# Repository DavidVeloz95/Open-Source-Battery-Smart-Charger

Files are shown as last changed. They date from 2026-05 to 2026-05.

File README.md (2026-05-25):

# Open Battery Smart Charger

Smart 2S Li-Ion battery charger designed in KiCad featuring input protection, power-path management, and intelligent charging control.

---

## Overview

This project implements an intelligent battery charging system for **2-cell Li-Ion batteries (8.4V)** with integrated protection and automatic power switching.

The system combines:

- Smart charging control
- Input overvoltage and overcurrent protection
- Automatic source/battery switching
- Auxiliary regulated 3.3V rail
- Battery monitoring interfaces

The design was developed in **KiCad 10** as part of a hardware/electronics engineering portfolio project.

---

## Features

- 2S Li-Ion battery charging (8.4V)
- Constant-current / constant-voltage (CC/CV) charging
- Input surge and fault protection
- Power-path management between external supply and battery
- Reverse current protection
- 3.3V regulated output for embedded systems
- Thermistor input for battery temperature supervision
- System and battery voltage interfaces

---

## System Architecture

### 1. Input Protection Stage

The input stage is protected using the **TPS26600** eFuse, providing:

- Overvoltage protection (OVP)
- Current limiting
- Fault protection
- Hot-plug robustness

This stage protects downstream electronics from abnormal supply conditions.

### 2. Smart Battery Charger

Battery charging is managed using the **LT3650**, configured for:

- 2S Li-Ion battery charging
- Constant-current / constant-voltage charging profile
- Battery temperature monitoring
- Charging status feedback

### 3. Power Path Management

The **LTC4412** controller enables automatic switching between:

- External DC power source
- Battery supply

This ensures uninterrupted system operation while preventing reverse current paths.

### 4. Auxiliary Power Rail

A dedicated **3.3V LDO regulator** powers low-voltage logic and embedded systems.

---

## Main Components

| Component | Function |
|---|---|
| LT3650 | Smart battery charger |
| TPS26600 | Input protection / eFuse |
| LTC4412 | Ideal diode power-path controller |
| LDK320AM33R | 3.3V voltage regulator |

---

## Specifications

| Parameter | Value |
|---|---|
| Battery Type | 2S Li-Ion |
| Charge Voltage | 8.4V |
| Charging Method | CC/CV |
| Logic Rail | 3.3V |
| Input Protection | OVP / current limiting |
| Design Tool | KiCad 10 |

---

## Repository Structure

```text
Open_Battery_Charger/
│
├── hardware/
│   ├── Open_Battery_Charger.kicad_pro
│   ├── Open_Battery_Charger.kicad_sch
│   ├── Open_Battery_Charger.kicad_pcb
│   └── fp-lib-table
│
├── docs/
│   ├── schematic.pdf
│   ├── schematic.png
│   ├── 2D_pcb_top.png
│   ├── 2D_pcb_bottom.png
│   ├── 3D_pcb_top.png
│   ├── 3D_pcb_bottom.png
│   ├── Detailed_Design_Procedure_LT3650.pdf
│   ├── Detailed_Design_Procedure_TPS2660
│   └── Open_Source_Battery_Smart_Charger_Specifications.pdf
│
└── production/
    ├── gerbers/
    └── bom.csv
```

---

## Schematic

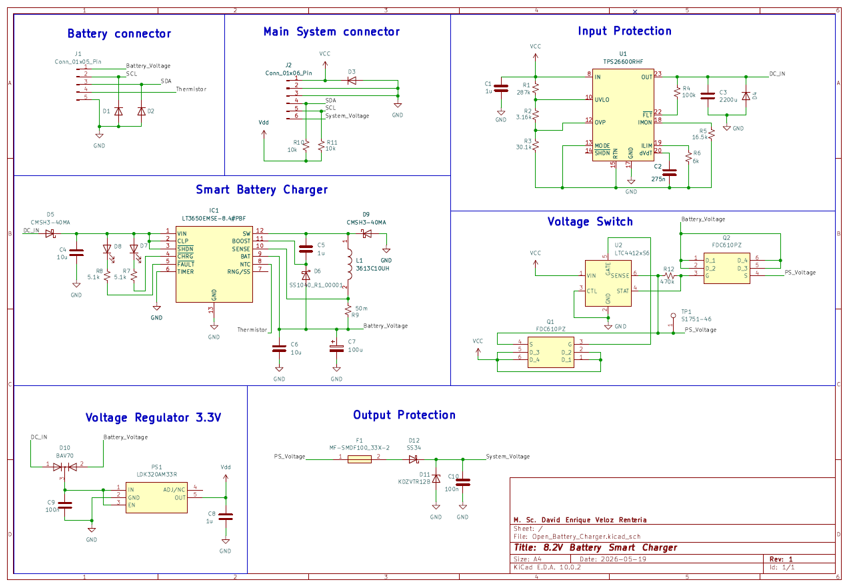
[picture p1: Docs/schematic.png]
Schematic


---

## PCB Design

### Top View

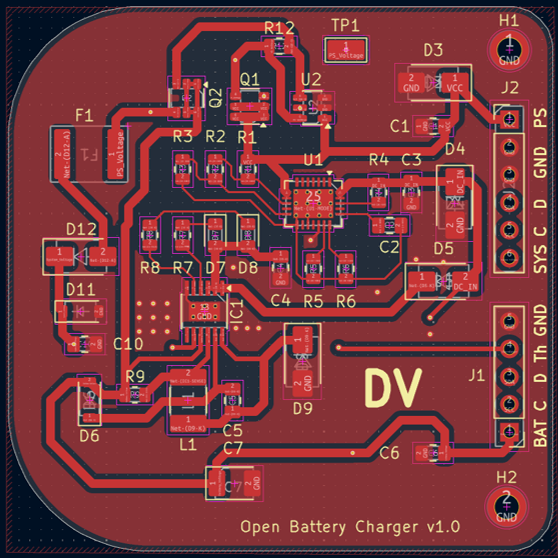
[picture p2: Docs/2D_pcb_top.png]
PCB Top


### 3D Render

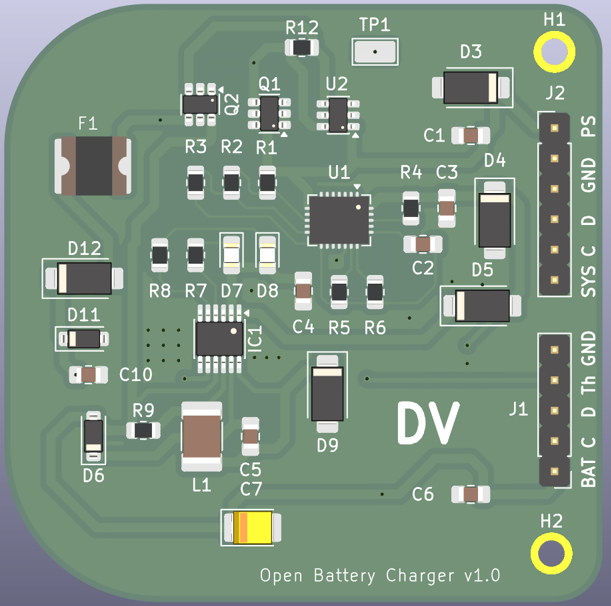
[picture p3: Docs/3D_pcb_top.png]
PCB Render


---

## Design Considerations

Key engineering decisions considered during development:

- Input fault protection for safer operation
- Efficient battery charging profile implementation
- Automatic power source switching
- Low-voltage regulation for embedded systems
- Modular architecture for maintainability

---

## Tools

- KiCad 10
- Datasheet-driven design methodology
- Electronic circuit validation

---

## Future Improvements

- PCB manufacturing and validation
- Thermal characterization
- Charging efficiency measurements
- Test reports and oscilloscope captures
- Firmware integration for battery monitoring

---

## License

This project is released under the MIT License.

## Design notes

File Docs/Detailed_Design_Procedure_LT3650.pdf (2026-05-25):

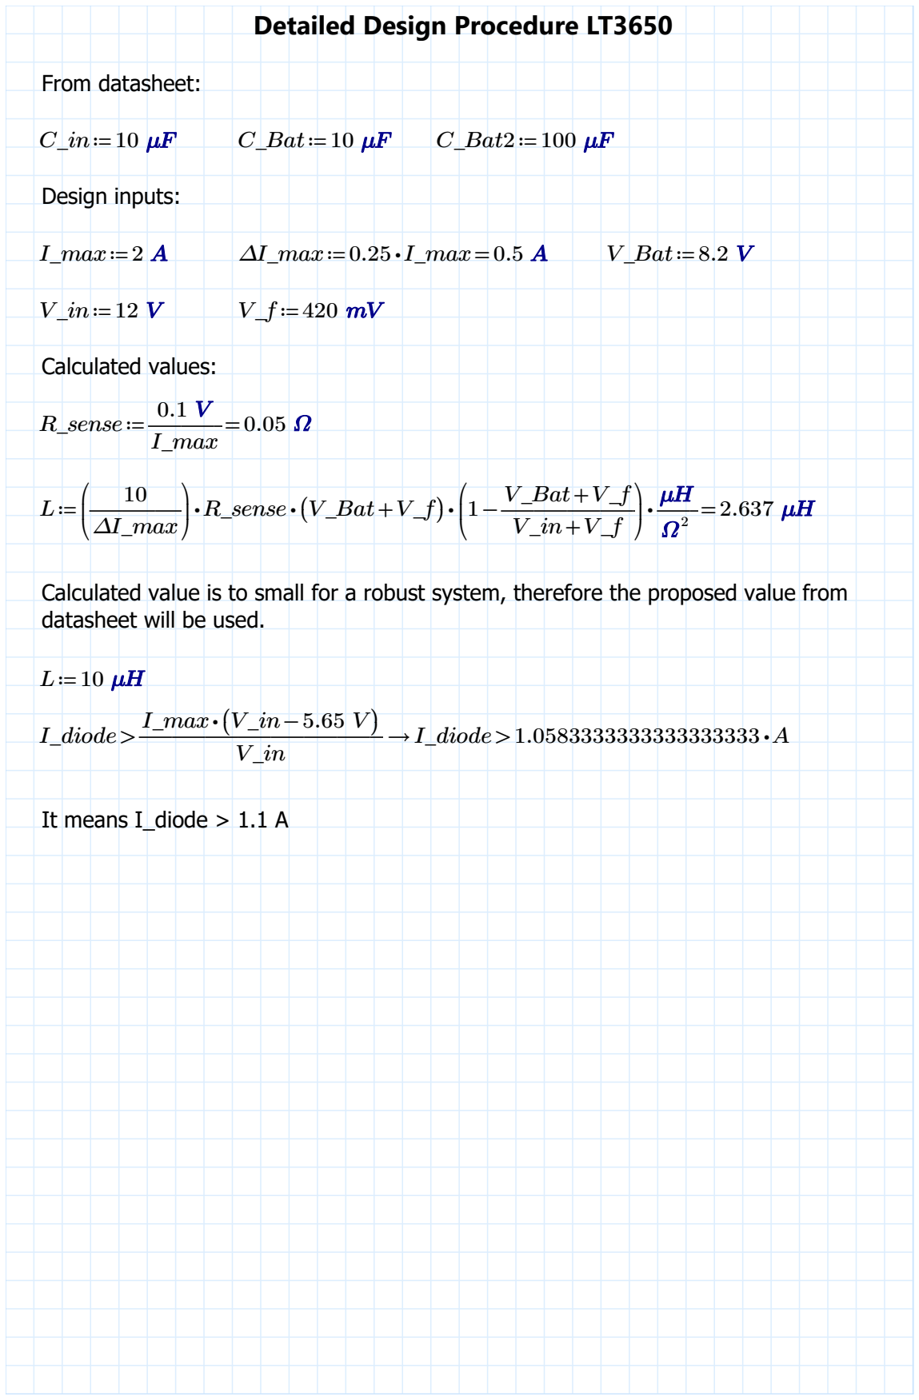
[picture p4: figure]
Detailed Design Procedure LT3650; From datasheet:; C_Bat≔10 μF; C_Bat2≔100 μF; Design inputs:; Calculated values:; R_sense≔―――=; 0.1 V I_max; ― ΔI_max; R_sense; ((V_Bat+V_f)); 1-―V_Bat ――+V_f ―― V_in+V_f; datasheet will be used.; I_diode>――――――――→; I_max⋅ ((V_in-5.65; I_diode>1.0583333333333333333 ⋅A; It means I_diode > 1.1 A

I_max≔2 A | ΔI_max≔0.25 ⋅ I_max=0.5 A | V_Bat≔8.2 V

Calculated value is to small for a robust system, therefore the proposed value from

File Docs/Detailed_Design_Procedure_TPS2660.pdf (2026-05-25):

### Detailed Design Procedure TPS2660

Design parameters:
Vin = 12V
Vov = 12.6V
Vuv = 11.4V
RL(su) = 12Ω
Ilim = 2A
Cout = 2200μF

Undervoltage Lockout and Overvoltage Protection

From datasheet V_ovpr = 1.19V and V_uvlor = 1.19V.

V_ovpr≔1.19 V | V_uvlor≔1.19 V

Overvoltage protection (Ov = 12.6V) and Undervoltage protection (Uv = 11.4V). Values are from power supply (AKM45US12).

Ov≔12.6 V | Uv≔11.4 | V
Resistor values calculated starting with R3 = 30.1 kΩ | and equations from datasheet.
X = R1+R2+R3.
R3≔30.1 | kΩ | X≔―――⋅ | =

R3
V_ovpr
| | | | Ov 318.706 | kΩ
R2≔―――⋅ | - | =

V_uvlor
Uv
X | R3 | 3.168 | kΩ | R1≔X-R2-R3=285.437 | kΩ

Looking for real resistor values (case code 0805 in) available on Mouser Electronics:

R1≔287 kΩ | R2≔3.16 kΩ | R3≔30.1 kΩ

Calculating new Voltage values:

V_ov≔V_ovpr ⋅―――――=

((R1+R2+R3))
| | R3 | | 12.661 V

V_uv≔V_uvlor ⋅―――――=

((R1+R2+R3))
R2+R3
| | | | 11.458 V

Active Current Limiting

Propossed System max. current (2A) shall be the limit. The equation comes from datasheet:

I_ol≔2 A | R_ilim≔―――=
| | | | 12 kV I_ol 6 kΩ

Using a real resistor value R_ilim = 6 kΩ:

R_ilim≔6 | kΩ | I_lim≔―――=

### 12 kV

R_ilim

### 2 A

Input noise suppress

C_in has a typical capacitance value in range of 0.1 | μF to 1 | μF.

C_in≔1 μF

Current Monitoring Resistor

For I_lim=2A, and considering the operating voltage range of ADC from 0V to 2.5V:

V_IMONmax≔2.5 V

R_IMON≔――――――=

V_IMONmax
I_lim⋅ ⎛⎝75 ⋅ 10⁻⁶⎞
⎠
16.667 | kΩ | V≔I_lim⋅ ⎛⎝75 ⋅ 10 | ⋅ | =

-6⎞
⎠ | 16.5 kΩ | 2.475 | V

Real value for R_IMON:

R_IMON≔16.5 kΩ

Output Voltage Ramp Time

For an inrush current I_inrush=1A (estimated) shall be the t_dVdT calculated:

I_inrush≔1 A | C_out≔2200 μF | V_in≔12 | V

t_dVdT≔C_out⋅―――=

| | V_in
I_inrush
| | 65.34 ms

For a given start-up time, C_dVdT capacitance value is calculated: C_dVdT≔―t_dVdT ――⋅―1 A― ⋅ ⎛⎝8 ⋅ 10³ ⎞
⎠ V_in
| | C_dVdT=275 nF

The pull-up resistor (R4 or R_fltb) for the open-drain fault output shall have a value in
the range of 10 kΩ | to 100kΩ. The current sink by pin FLT must not exceed 10mA.
R_fltb≔100 | kΩ | I_flt≔―――=
| | 12 V R_fltb 0.297 mA

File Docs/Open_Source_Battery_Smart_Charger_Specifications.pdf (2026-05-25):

REFERENCE DESIGN – PORTFOLIO USE ONLY | DV

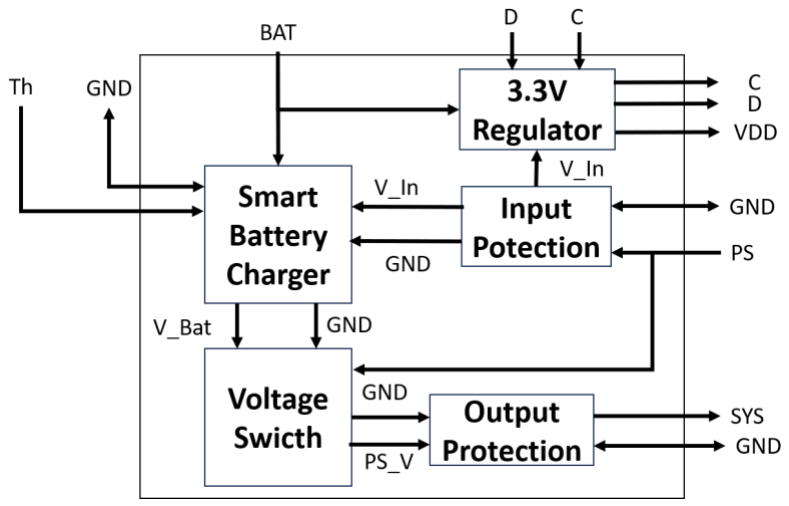
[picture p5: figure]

Revision: 1.0 Date: May 2026 This document is intended solely for engineering portfolio and reference purposes. © M. Sc. David Veloz. All rights reserved.

## Open-Source Battery Smart Charger Specifications

### 1. General Description

This design is intended to provide a flexible platform for providing power to an external device using 2S Li-Ion batteries or external DC Voltage source. The module provides 8.2V – 12V power to the external system continually whilst a battery pack or external DC supply is connected.

### 2. Board Overview

### 2.1. Architecture Block Diagramm

Figure 1: Architecture Block Diagramm.

### 2.2. Signal Description

Signal Name | Description
PS | Main power supply for the circuit
GND | Ground reference
BAT | Battery voltage
Th | Analog thermistor signal
SYS | System Power Supply
VDD | 3.3V regulated power supply
C | I2C bus clock line
D | I2C bus data line
Table 1: Signal Description.

### 2.3. Pin Configuration Battery Connector (J1)

Pin
No.
Symbol | Type
1 | BAT | Battery Power
2 | C | Digital Clock
3 | D | Digital Bidirectional Data
4 | Th | Analog Sense
5 | GND | Ground Reference
Table 2: Battery Connector Pin Definition.

### 2.4. Pin Configuration System Connector (J2)

Pin
No.
Symbol | Type
1 | PS | Power Supply
2 | GND | Ground Reference
3 | GND | Ground Reference
4 | D | Digital Bidirectional Data
5 | C | Digital Clock
6 | SYS | External System Power Supply
Table 3: System Connector Pin Definition.

### 3. Mechanical Specifications

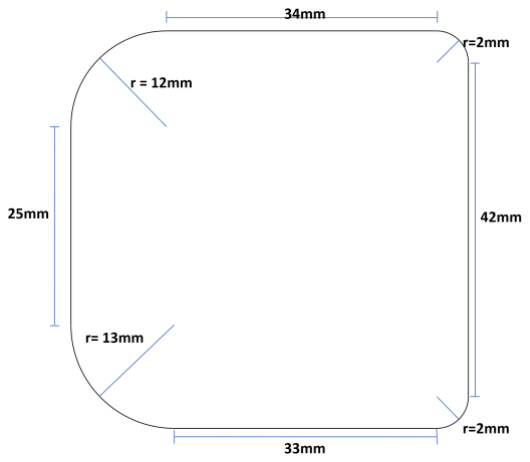
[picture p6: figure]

Figure 2: Board Dimensions.

### 4. Reference Schematics

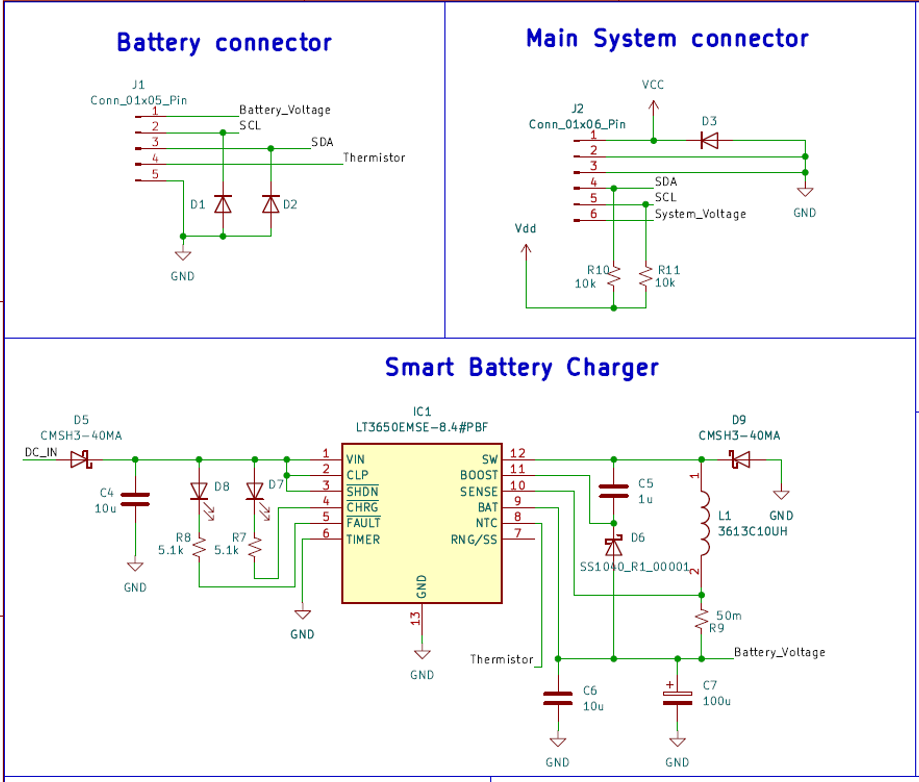
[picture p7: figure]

Figure 3: Connectors and Battery Charger circuitry.

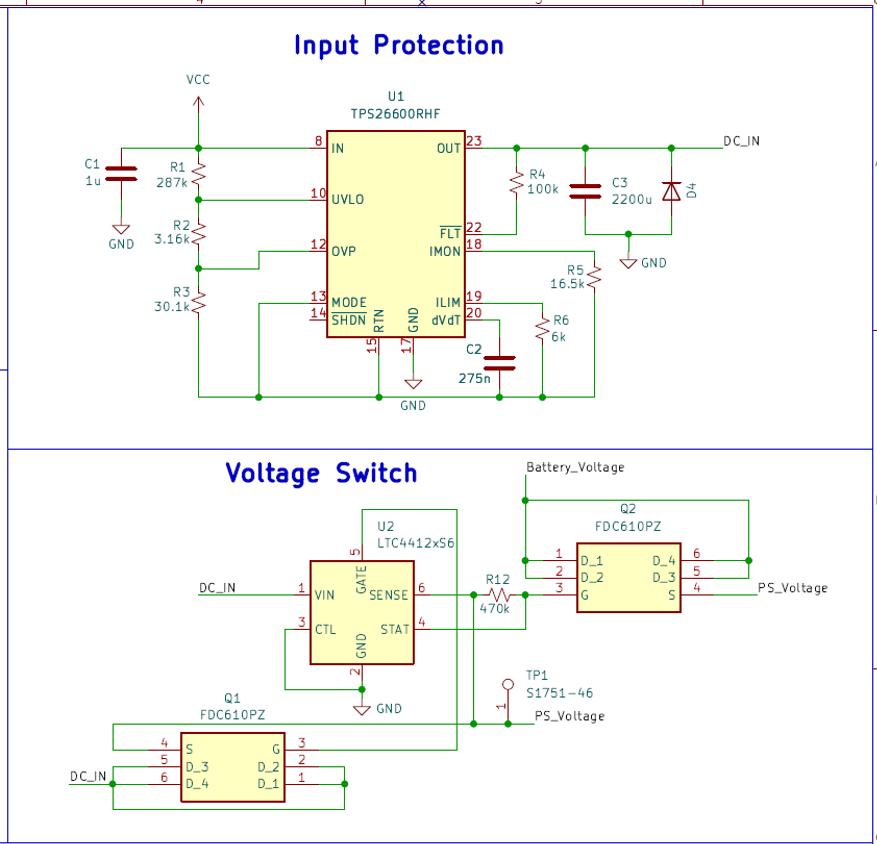
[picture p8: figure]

Figure 4: Input protection circuit and voltage switcher.

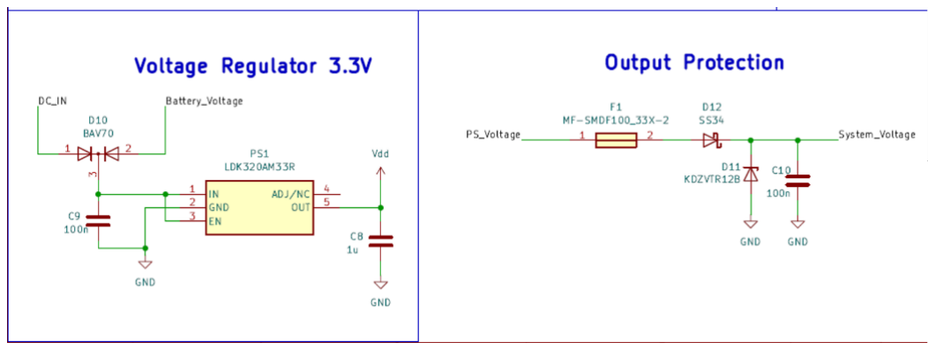
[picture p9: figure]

Figure 5: 3.3V Regulator and output protection circuit.

### 5. Board Specifications 5.1. Absolute Maximum Ratings, TA=25°C

Parameters | Min. | Max. | Unit
Supply Voltage | 12 | 12 | V
Input Over Voltage Protection | - | 12.6 | V
Charging Voltage | - | 8.4 | V
Charging Current | - | 2000 | mA
Charge mode | CC/CV
Reverse polarity protection | Yes
Thermistor support | Yes
Input Fuse | 1A polyfuse
Logic I2C Voltage | - | 3.3 | V
Table 4: Electrical Specifications.

### 6. Main Components Specifications 6.1. Input Protection (TPS26600)

The circuitry is protected from the connection from an incompatible DC Power Supply. The protection circuit has the following features:
- Undervoltage Lockout at 11.4V
- Overvoltage protection at 12.6V
- Reverse current blocking

To reach the features a TPS26600 was selected. Circuitry, shown on Figure 4 – Input Protection, is the TPS26600 configuration to protect load from overvoltage, reverse voltage, etc.

Passive components were calculated following the next procedure:

System design parameters:

Vin = 12V
VOV = 12.6V
VUV = 11.4V
RL(su) = 12Ω
Ilim = 2A
COut = 2200μF

Undervoltage Lockout and Overvoltage Protection

From Datasheet VOVPR = 1.19V and VUVLOR = 1.19V.

Overvoltage protection (VOV = 12.6V) and Undervoltage protection VUV = 11.4V. Values come from power supply (AKM45US12). Resistor values calculated starting with R3 = 30.1kΩ and equations from datasheet.

X = R1 + R2 + R3

X =

R3

VOVPR

= 318.706 kΩ

R2 =

VUVLOR

VUV

= 3.168 kΩ

R1 = X − R2 − R3 = 285.437 kΩ

Looking for real resistor values with case code 0805 (in) available on Mouser Electronics:

R1 = 287 kΩ
R2 = 3.16 kΩ
R3 = 30.1 kΩ
Calculating new voltage values:

VOV = VOVPR ∙

R1 + R2 + R3
R3

= 12.661 V

VUV = VUVLOR ∙

R1 + R2 + R3
R2 + R3

= 11.458 V

Active Current Limiting

Proposed System max. current (2A) shall be the limit. The equations are from datasheet:

Rilim =

12

Ilim

= 6 kΩ

Input noise suppression

CIn has a typical capacitance value in range of 0.1μF to 1μF.

CIn = 1μF

Current Monitoring Resistor

For Ilim = 2A, and considering the operation voltage range of ADC from 0V to 2.5V:

VIMONmax = 2.5 V

RIMON =

VIMONmax
Ilim∙(75∙10⁻⁶)

= 16.667 kΩ V = Ilim ∙ (75 ∙ 10⁻⁶ ) ∙ 16.5 kΩ = 2.475 V

Real value for RIMON = 16.5 kΩ

Output Voltage Ramp Time

For an inrush current Iinrusℎ = 1 A (estimated) shall be the tdVdT calculated:

tdVdT = COut ∙

VIn

Iinrusℎ

= 65.34 ms

For a given start-up time, CdVdT capacitance value is calculated:

CdVdT =

tdVdT
(8 ∙ 10³) ∙ VIn

= 275 nF

The pull-up resistor (R4 or Rfltb) for the open-drain fault output shall have a value in the range of 10 kΩ to 100 kΩ. The current sink by pin FLT must not exceed 10 mA.

Rfltb = 100 kΩ

Iflt =

12V

Rftlb

= 0.297 mA

### 6.2. Battery Charger (LT3650-8.4)

The battery pack can be charged from an external 12V ACDC power supply. For design the LT3650-8.4 was selected. Some features of the controller are:
- Constant-Current/constant-voltage charge
- 2A charging current
- Low battery and bad-battery detection
- Auto-restart mode if the battery voltage drops 2.5%

The LT3650 is a Li-Ion battery charger, which incorporates a 2 A switch that is driven by a bootstrapped supply to maximize efficiency during charging cycles. Once charging is terminated and the LT3650 is not actively charging, the IC automatically enters a low current standby mode in which supply bias currents are reduced to 85 μA. The IC monitors battery temperature by using a thermistor during charging cycle, suspends charging, and signals a fault condition if the battery temperature moves outside a safe charging range.

Passive components were calculated following the next procedure:

From datasheet we got the next values

Cin = 10 μF CBat = 10 μF CBat2 = 100 μF

The design inputs for this circuitry are:

Imax = 2 A | ΔImax = 0.25 ∙ Imax = 0.5 A VBat = 8.2 V Vin = 12 V | Vf = 420 mV

Then the calculated values for passive components are:

Rsense =

0.1 V

Imax

= 0.05 Ω

L = (

10

ΔImax

) ∙ Rsense ∙ (VBat + Vf) ∙ (1 − VBat + Vf

VIn + Vf

) = 2.637 μH

The calculated value is to small for a robust system, therefore the proposed value from datasheet will be used.

L = 10 μH

For diode election the next value is needed:

Idiode >

Imax ∙ (VIn − 5.65)

VIn

~1.0583 A

It means the Idiode > 1.1 A

### 6.3. Voltage Switch (LTC4412)

The LTC4412 controls an external P-Channel MOSFET for power switchover. When a wall adapter is connected the load is automatically disconnected from the battery. For this design the primary supply is the wall adapter. The capability of the automatic controller makes it feasible to use the IC without an external microcontroller.

### 6.4. Output Protection

The fuse used protects the circuit from overcurrents and short circuits; it does not blow or suffer permanent damage but is capable of automatically resuming normal operation after cooling down. In addition, a Schottky diode is used to provide reverse current protection, along with a Zener diode and a capacitor in parallel to prevent overvoltage clamping, absorb spikes, reduce ringing, and improve transient stability.

### 6.5. Voltage Regulator

The LDK320 is a voltage regulator, which provides a 3.3V output. The very good dynamic characteristic, combined with low drop voltage and low quiescent current make it suitable for this application. This device also includes short-circuit current limiting, thermal and safe operating area protection.

### 7. Performance

To verify that this circuit is working properly, the ideal outcome would be to obtain the following results.
- Full battery charge, with graphs showing Battery Charging Current (Ampere) vs Battery Charging Time Percentage (%); Battery Charging Current (Ampere) vs Battery Voltage (Voltage); Temperature (Celsius degree) while Battery Charging (%); Battery Voltage
(Voltage) while Battery charging (%); Power Supply Current (Ampere) while Battery charging (%); Power comparison (W) between circuit input (Power Supply) and output

(Battery) during charging process; Efficiency (%) vs Battery Charging Time Percentage (%).
- Battery discharge, graphically representing Temperature (°c) while Battery discharging; Battery Voltage while discharging with different loads.
- Simultaneous connection of the power supply and the fully charged battery, graphically representing efficiency.
- Battery discharge with loads varying over time, graphically representing performance.

### 8. Bill Of Materials

Reference | Value
C1,C5,C8 | 1u
C2 | 275n
C3 | 2200u
C4,C6 | 10u
C7 | 100u
C9,C10 | 100n
D1,D2,D3,D4 | SMAJ12A-HP6AT/13
D5,D9 | CMSH3-40MA
D6 | SS1040_R1_00001
D7 | Q62702P5179
D8 | Q62702P5178
D10 | BAV70
D11 | KDZVTR12B
D12 | SS34
F1 | MF-SMDF100_33X-2
IC1 | LT3650EMSE-8.4#PBF
J1 | Conn_01x05_Pin
J2 | Conn_01x06_Pin
L1 | 3613C10UH
PS1 | LDK320AM33R
Q1,Q2 | FDC610PZ
R1 | 287k
R2 | 3.16k
R3 | 30.1k
R4 | 100k
R5 | 16.5k
R6 | 6k
R7,R8 | 5.1k
R9 | 50m
R10,R11 | 10k
R12 | 470k
TP1 | S1751-46
U1 | TPS26600RHF
U2 | LTC4412xS6

### 9. Test Procedures 9.1. Funcitional Test

1. Do a visual inspection, verifying all connectors are well welded according to IPC-A-610E SP, all IC’s are correctly oriented, if PCB has scratches or any mechanical damage, also look for solder bridges.
2. Verify that J1 pin 1 (Battery_Voltage), J2 pin 1 (VCC) and pin 6 (System_Voltage), IC1 pin 1 (DC_IN), TP1 and connection between D1, D2, D3, D4, D9, D11 have non-connectivity with GND.
3. Connect J2 to AC/DC Wall Adapter 12V. D8 LED shall be OFF the whole time.
4. TP1 should have a value around 12V.
5. Connect a multimeter and an electric load at 2A to J2 (System_Voltage and GND).
6. Turn on the electronic load and look at the output voltage in oscilloscope. Voltage must be around 11.5V.
7. Turn off the electric load and disconnect J2 and connect battery pack to J1. D7 must turn on if Power Supply and Battery are connected simultaneously.
8. Repeat procedure instructions 4 to 6. But Voltages shall be between 5.2V and 8.4V.
9. Disconnect battery.

### 9.2. Discharging Test

1. Before continuing with this test, the functional test shall be approved.
2. Be sure Battery is full.
3. During this test is important to get the next values:
a. Battery current in Amperes.
b. Battery voltage in Volts.
c. Power Supply current in Amperes.
d. Power Supply voltage in Volts.
e. Temperature in Celsius.
4. To acquire each value is needed to use a specific connection. Connections shall be explained only if this board is manufactured because external custom boards or harnesses would be needed.
5. Connect harness at J2.
6. Identify System_Voltage and GND pins. Connect an electric load to them.
7. Connect the battery and set the electric load at 2A.
8. After doing the connections to measure data, turn on the electric load.
9. When battery is empty, turn off the electric load and stop data acquisition. Save the data.
10. Disconnect all and storage the equipment as specified in laboratory instructions.

### 9.3. Charging Test

1. Before continuing with this test, the functional test shall be approved.
2. Be sure Battery is empty.
3. During this test is important to get the next values:
a. Battery current in Amperes.
b. Battery voltage in Volts.
c. Power Supply current in Amperes.

d. Power Supply voltage in Volts.
e. Temperature in Celsius.
4. To acquire each value is needed to use a specific connection. Connections shall be explained only if this board is manufactured because external custom boards or harnesses would be needed.
5. Connect harness at J2.
6. Connect the battery and the Power Supply. Harness J2 will have a DC Jack connector.
7. Connect Power Supply to AC Socket.
8. When battery is full, disconnect Power Supply and stop data acquisition. Save the data.
9. Disconnect all and storage the equipment as specified in laboratory instructions.

### 10.Equipment needed

The equipment needed to run the tests to this circuit is:
- Digital Multimeter
- Power Supply or Voltage Generator
- Temperature sensor
- Electronic Load

### 11.Design Inputs

Requirement: The circuit should be protected from the connection from an incompatible DC Power Supply. The protection circuit should have the following features:
- Reverse Polarity Protection
- Overvoltage protection
Actions: TPS26600 provides over voltage protection at 12.6V since it is considered that Power Supplies normally have variations at output, having a protection exactly at 12 V will limit the supplies that can be used, while operating range is 60V and reverse input polarity protection is -60V.

Requirement: The battery should be charged from an external 12V ACDC power supply. A compatible barrel jack connector should be used with the DC Supply.
Actions: Components are configured to work with an external 12V ACDC Power Supply (AKM45US12).

Requirement: The board should pass the output voltage directly from the charging circuit to the device output without alteration.
Actions: There is no internal regulator for main voltage output. Value at input is almost the same value at the output, it depends on the characteristics from Supply with a load.

Requirement: SMBus pins should be exposed on the output connector. Logic levels should be 3.3V. Actions: Communication logical voltage is provided by LDK320AM33R.

Requirement: The output of the board should be protected in such a way that failure in either the external load or the board itself should not damage the other module.
To mitigate this risk the board should provide the following output protection features.
- Overcurrent protection outside of supply specification.
- Over voltage protection outside of supply specification.

Actions: To solve an unfortunate failure as overcurrent or over voltage there is a diode (KDZVTR12B) and fuse (MF-SMDF100_33X-2) arrangement to provide protection to module that is connected to the board.

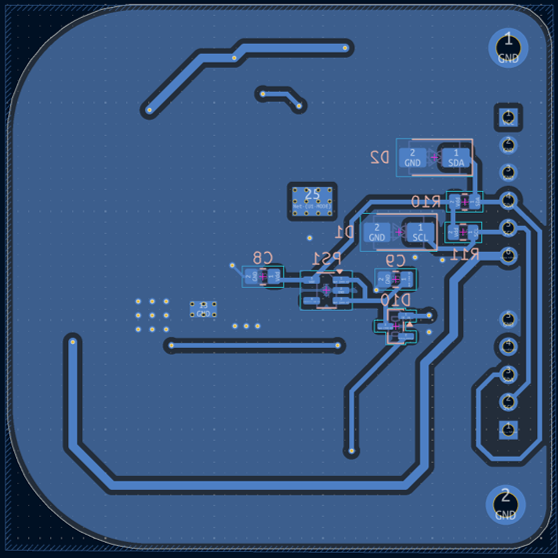
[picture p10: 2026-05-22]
Docs/2D_pcb_bottom.png

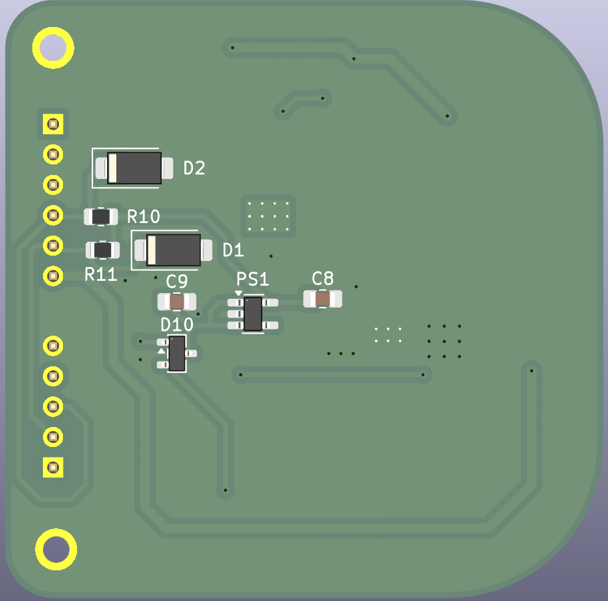
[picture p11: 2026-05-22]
Docs/3D_pcb_bottom.png

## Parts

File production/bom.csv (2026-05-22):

Bill Of Materials (BOM)
# | Reference | Qty | Value | Descripción | Product Number | Manufacturer | Price
1 | C1,C5,C8 | 3 | 1u | Unpolarized capacitor
2 | C2 | 1 | 275n | Unpolarized capacitor
3 | C3 | 1 | 2200u | Unpolarized capacitor
4 | C4,C6 | 2 | 10u | Unpolarized capacitor
5 | C7 | 1 | 100u | TLJP107M004R2700
6 | C9,C10 | 2 | 100n | Unpolarized capacitor
7 | D1,D2,D3,D4 | 4 | SMAJ12A-HP6AT/13 | ESD Protection Diodes / SMAJ DO214AC TVS Diodes 12V–19.9V AEC-Q101 | SMAJ12A-HP6AT/13 | YAGEO | 0,396
8 | D5,D9 | 2 | CMSH3-40MA | Schottky diode
9 | D6 | 1 | SS1040_R1_00001 | Schottky diode
10 | D7 | 1 | Q62702P5179 | Light emitting diode
11 | D8 | 1 | Q62702P5178 | Light emitting diode
12 | D10 | 1 | BAV70 | Dual 100V 215mA high-speed switching diodes, common cathode, SOT-23
13 | D11 | 1 | KDZVTR12B | Zener diode
14 | D12 | 1 | SS34 | 40V 3A Schottky Diode, SMA
15 | F1 | 1 | MF-SMDF100_33X-2 | Resettable Fuses - PPTC PTC RESETTABLE 1.1A 33V SMD 2018
16 | IC1 | 1 | LT3650EMSE-8.4#PBF | Battery Management High Voltage 2 Amp Monolithic 2-Cell Li-Ion Battery Charger
17 | J1 | 1 | Conn_01x05_Pin | Generic connector, single row, 01x05, script generated
18 | J2 | 1 | Conn_01x06_Pin | Generic connector, single row, 01x06, script generated
19 | L1 | 1 | 3613C10UH | Fixed Inductors 250 mAmps +/- 10% 10 uH
20 | PS1 | 1 | LDK320AM33R | LDO Voltage Regulators 200 mA low quiescent current and high PSRR voltage regulator
21 | Q1,Q2 | 2 | FDC610PZ | Max rDS(on) = 75m at VGS = -4.5V, ID = -3.7A; Low gate charge (17nC typical).; High performance trench technology for extremely low rDS(on). ; SuperSOT-6 package: small footprint (72% smaller than standard SO-8) low profile (1mm thick).; Max rDS(on) = 42m at VGS = -10V, ID = -4.9A; RoHS compliant
22 | R1 | 1 | 287k | Resistor, small US symbol
23 | R2 | 1 | 3.16k | Resistor, small US symbol
24 | R3 | 1 | 30.1k | Resistor, small US symbol
25 | R4 | 1 | 100k | Resistor, small US symbol
26 | R5 | 1 | 16.5k | Resistor, small US symbol
27 | R6 | 1 | 6k | Resistor, small US symbol
28 | R7,R8 | 2 | 5.1k | Resistor, small US symbol
29 | R9 | 1 | 50m | Resistor, small US symbol
30 | R10,R11 | 2 | 10k | Resistor, small US symbol,Thick Film Resistors - SMD General Purpose Chip Resistor 0805, 10kOhms, 5%, 1/8W | RC0805JR-7W10KL | YAGEO | 0,086
31 | R12 | 1 | 470k | Resistor, small US symbol
32 | TP1 | 1 | S1751-46 | Hardware: SMT Test Point 1.63x3.25mm 2mm high
33 | U1 | 1 | TPS26600RHF | 60V, 2A Current Limiting, Industrial eFuse, Reverse Current Blocking, Adjustable Overvoltage cut-off, Active Current Limiting, Circuit Breaker with auto-retry, VQFN-24
34 | U2 | 1 | LTC4412xS6 | Low Loss PowerPath Controller, TSOT-23-6

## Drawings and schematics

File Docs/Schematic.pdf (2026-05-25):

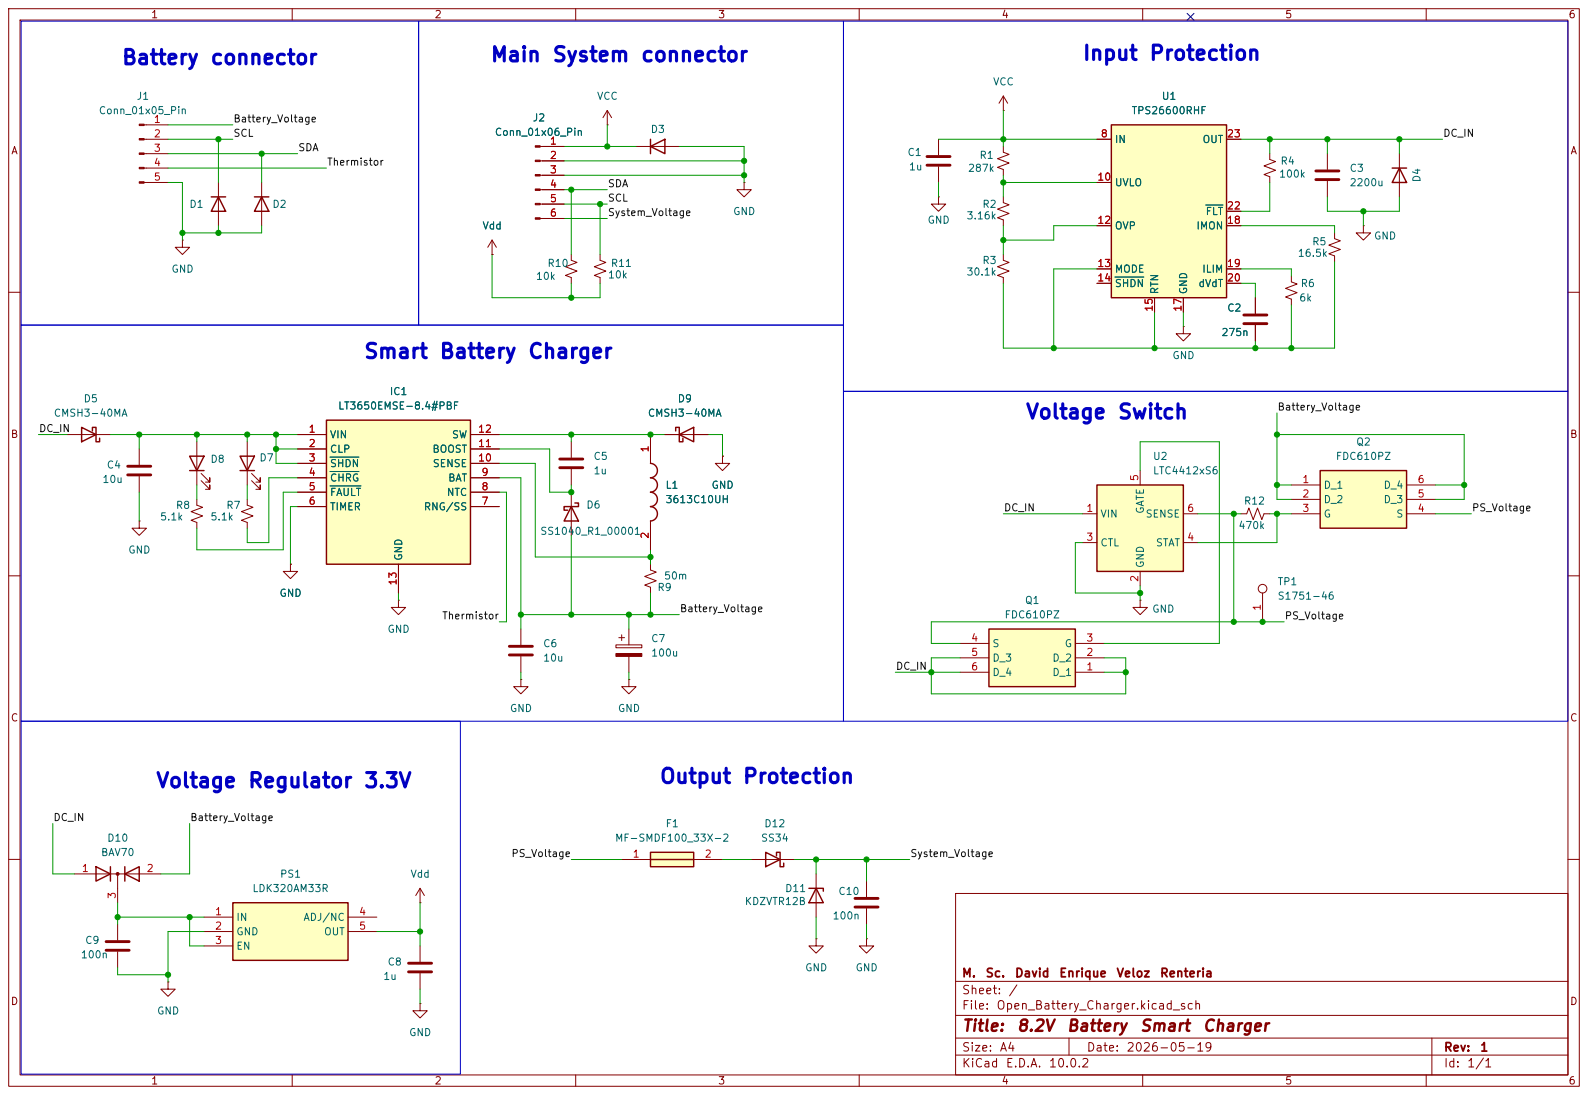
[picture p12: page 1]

M. Sc. David Enrique Veloz Renteria
Sheet: /
File: Open_Battery_Charger.kicad_sch
Title: 8.2V Battery Smart Charger

Size: A4 | Rev: 1
KiCad E.D.A. 10.0.2 | Id: 1/1

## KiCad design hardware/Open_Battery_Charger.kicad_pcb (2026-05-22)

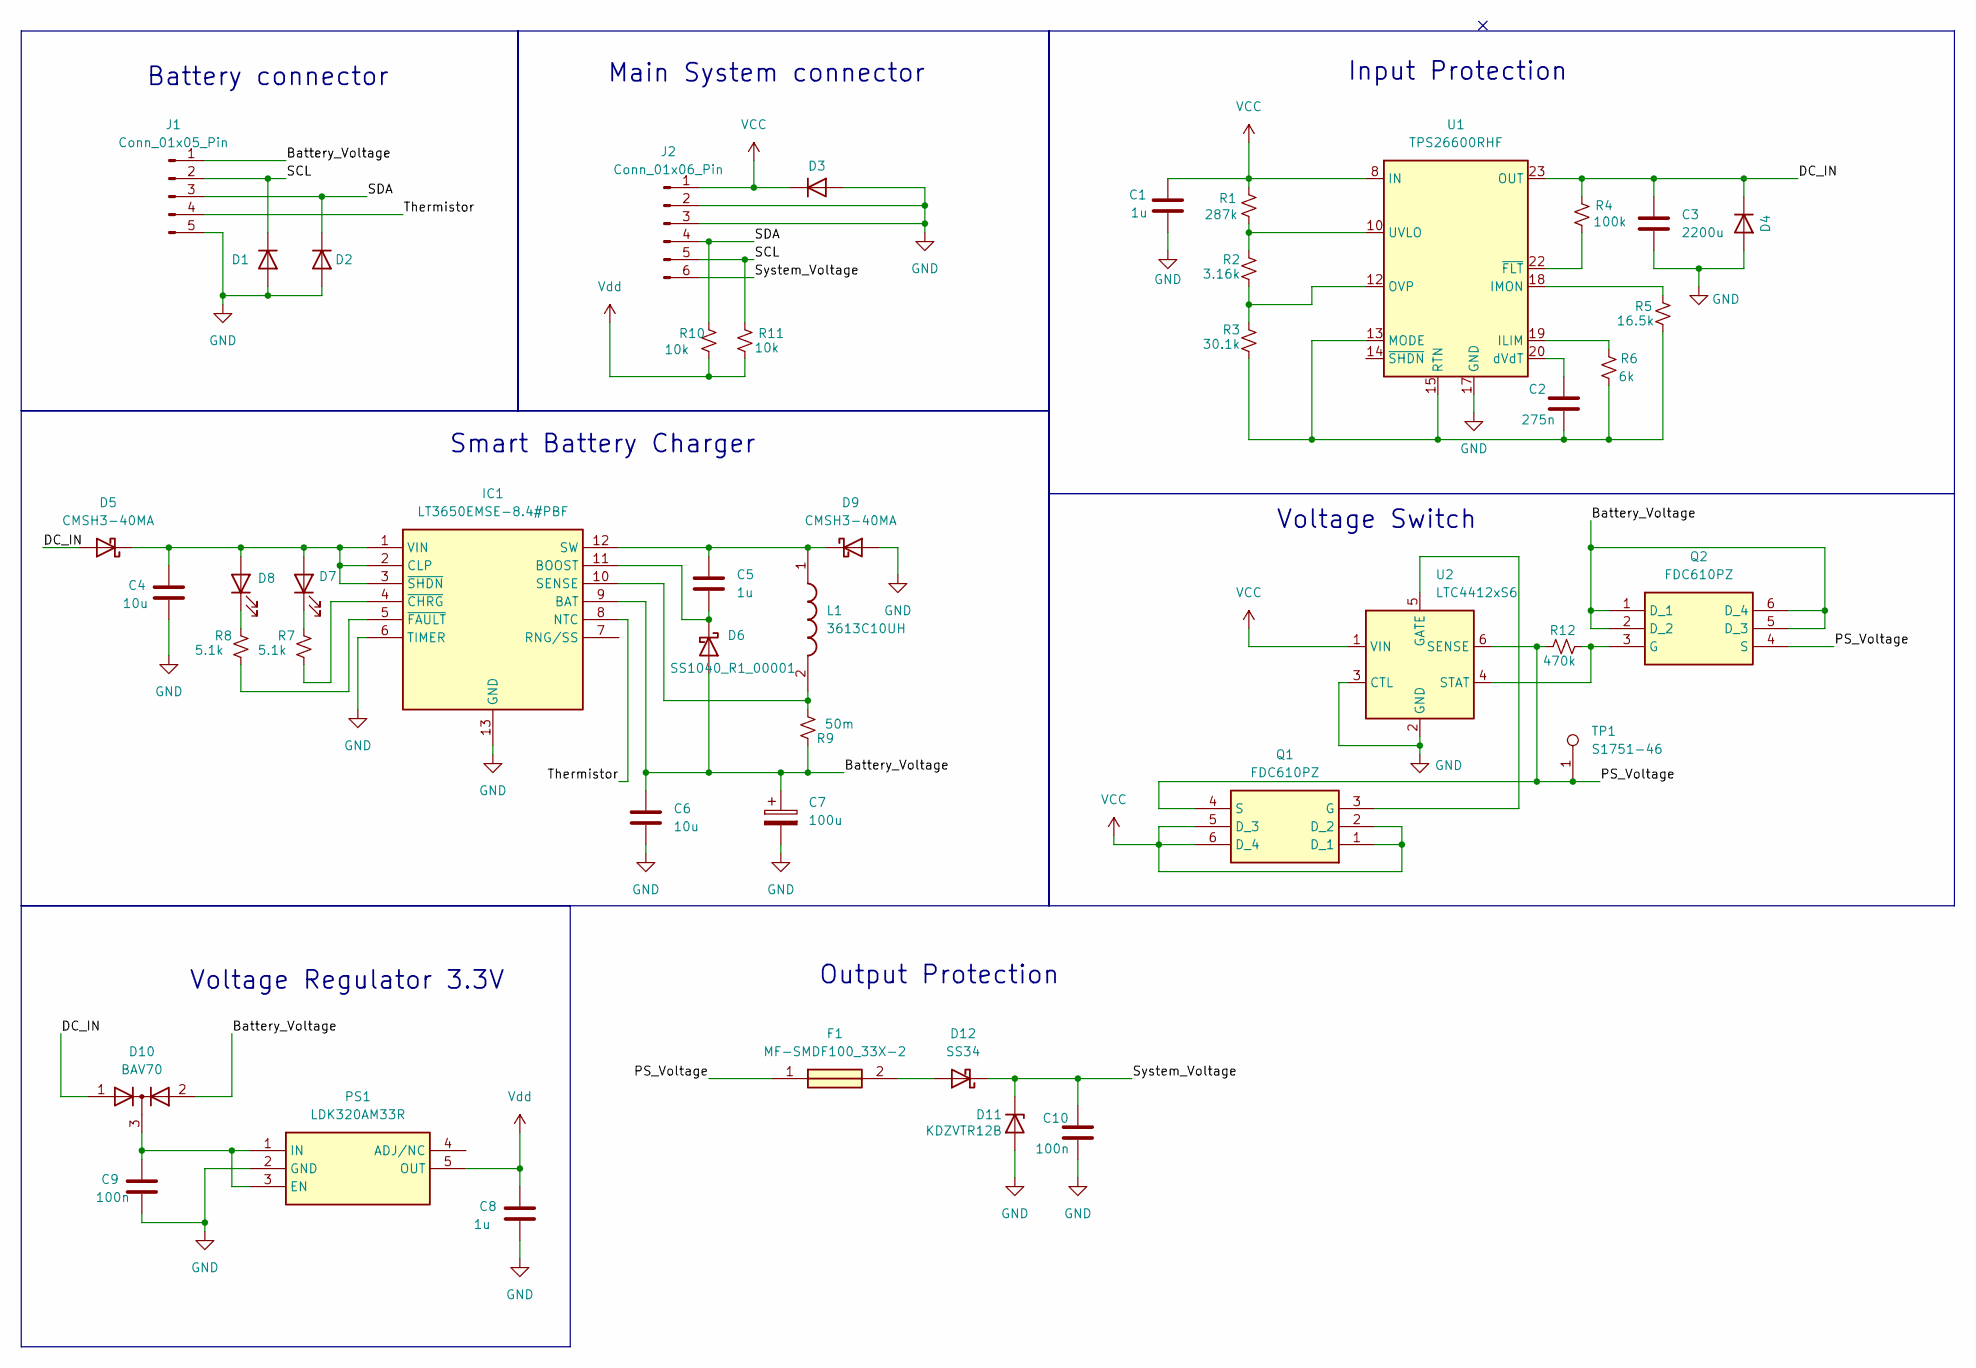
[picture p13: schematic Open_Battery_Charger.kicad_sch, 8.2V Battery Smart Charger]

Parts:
C1, C5, C8: 1u; C_0805_2012Metric_Pad1.18x1.45mm_HandSolder
C2: 275n; C_0805_2012Metric_Pad1.18x1.45mm_HandSolder
C3: 2200u; C_0805_2012Metric_Pad1.18x1.45mm_HandSolder
C4, C6: 10u; C_0805_2012Metric_Pad1.18x1.45mm_HandSolder
C7: 100u; CP_EIA-3528-21_Kemet-B_HandSolder
C9, C10: 100n; C_0805_2012Metric_Pad1.18x1.45mm_HandSolder
D1, D2, D3, D4: SMAJ12A-HP6AT/13; D_SMA
D5, D9: CMSH3-40MA; D_SMA
D6: SS1040_R1_00001; D_SOD-123
D7: Q62702P5179; LED_0805_2012Metric_Pad1.15x1.40mm_HandSolder
D8: Q62702P5178; LED_0805_2012Metric_Pad1.15x1.40mm_HandSolder
D10: BAV70; SOT-23
D11: KDZVTR12B; D_SOD-123
D12: SS34; D_SMA
F1: MF-SMDF100_33X-2; Mouser Part Number 652-MF-SMDF100/33X-2
IC1: LT3650EMSE-8.4#PBF; MSOP-12-1EP_3x4.039mm_P0.65mm_EP1.651x2.845mm_ThermalVias; Mouser Part Number 584-3650EMSE-8.4PBF
J1: Conn_01x05_Pin; PinHeader_1x05_P2.54mm_Vertical
J2: Conn_01x06_Pin; PinHeader_1x06_P2.54mm_Vertical
L1: 3613C10UH; C_1812_4532Metric_Pad1.57x3.40mm_HandSolder; Mouser Part Number 279-3613C10UH
PS1: LDK320AM33R; SOT-23-5_HandSoldering; Mouser Part Number 511-LDK320AM33R
Q1, Q2: FDC610PZ; SuperSOT-6; Mouser Part Number 512-FDC610PZ
R1: 287k; R_0805_2012Metric
R2: 3.16k; R_0805_2012Metric
R3: 30.1k; R_0805_2012Metric
R4: 100k; R_0805_2012Metric
R5: 16.5k; R_0805_2012Metric
R6: 6k; R_0805_2012Metric
R7, R8: 5.1k; R_0805_2012Metric
R9: 50m; R_0805_2012Metric
R10, R11: 10k; R_0805_2012Metric
R12: 470k; R_0805_2012Metric
TP1: S1751-46; TestPoint_Keystone_5015_Micro_Mini; Mouser Part Number 855-S1751-46
U1: TPS26600RHF; Texas_RHF0024A_VQFN-24-1EP_4x5mm_P0.5mm_EP2.65x3.65mm_Therm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
U2: LTC4412xS6; TSOT-23-6

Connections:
/Battery_Voltage: C6.1, C7.1, D6.2 (A), D10.2 (A), IC1.9 (BAT), J1.1, Q2.1 (D_1), Q2.2 (D_2), Q2.5 (D_3), Q2.6 (D_4), R9.1
/DC_IN: C3.1, D4.1 (K), D5.2 (A), D10.1 (A), R4.1, U1.23 (OUT), U1.24 (OUT)
/PS_Voltage: F1.1, Q1.4 (S), Q2.4 (S), R12.1, TP1.1, U2.6 (SENSE)
/SCL: D1.1 (K), J1.2, J2.5, R11.1
/SDA: D2.1 (K), J1.3, J2.4, R10.1
/System_Voltage: C10.1, D11.1 (K), D12.1 (K), J2.6
/Thermistor: IC1.8 (NTC), J1.4
GND: C1.1, C3.2, C4.2, C6.2, C7.2, C8.2, C9.2, C10.2, D1.2 (A), D2.2 (A), D3.2 (A), D4.2 (A), D9.2 (A), D11.2 (A), IC1.6 (TIMER), IC1.13 (GND), J1.5, J2.2, J2.3, PS1.2 (GND), U1.17 (GND), U2.2 (GND), U2.3 (CTL); also elsewhere on the board
unnamed: C4.1, D5.1 (K), D7.2 (A), D8.2 (A), IC1.1 (VIN), IC1.2 (CLP), IC1.3 (~SHDN)
unnamed: C5.2, D6.1 (K), IC1.11 (BOOST)
unnamed: D7.1 (K), R7.1
unnamed: D8.1 (K), R8.1
unnamed: C5.1, D9.1 (K), IC1.12 (SW), L1.1
unnamed: C9.1, D10.3 (K), PS1.1 (IN), PS1.3 (EN)
unnamed: D12.2 (A), F1.2
unnamed: IC1.10 (SENSE), L1.2, R9.2
unnamed: IC1.4 (~CHRG), R7.2
unnamed: IC1.5 (~FAULT), R8.2
unnamed: Q1.3 (G), U2.5 (GATE)
unnamed: Q2.3 (G), R12.2, U2.4 (STAT)
unnamed: R6.1, U1.19 (ILIM)
unnamed: R5.1, U1.18 (IMON)
unnamed: C2.2, R3.2, R5.2, R6.2, U1.13 (MODE), U1.15 (RTN), U1.25 (RTN)
unnamed: R2.2, R3.1, U1.12 (OVP)
unnamed: R1.2, R2.1, U1.10 (UVLO)
unnamed: C2.1, U1.20 (dVdT)
unnamed: R4.2, U1.22 (~FLT)
VCC: C1.2, D3.1 (K), J2.1, Q1.1 (D_1), Q1.2 (D_2), Q1.5 (D_3), Q1.6 (D_4), R1.1, U1.8 (IN), U1.9 (IN), U2.1 (VIN)
Vdd: C8.1, PS1.5 (OUT), R10.2, R11.2

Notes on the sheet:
Main System connector
Voltage Regulator 3.3V
Output Protection
Input Protection
Smart Battery Charger
Battery connector
Voltage Switch

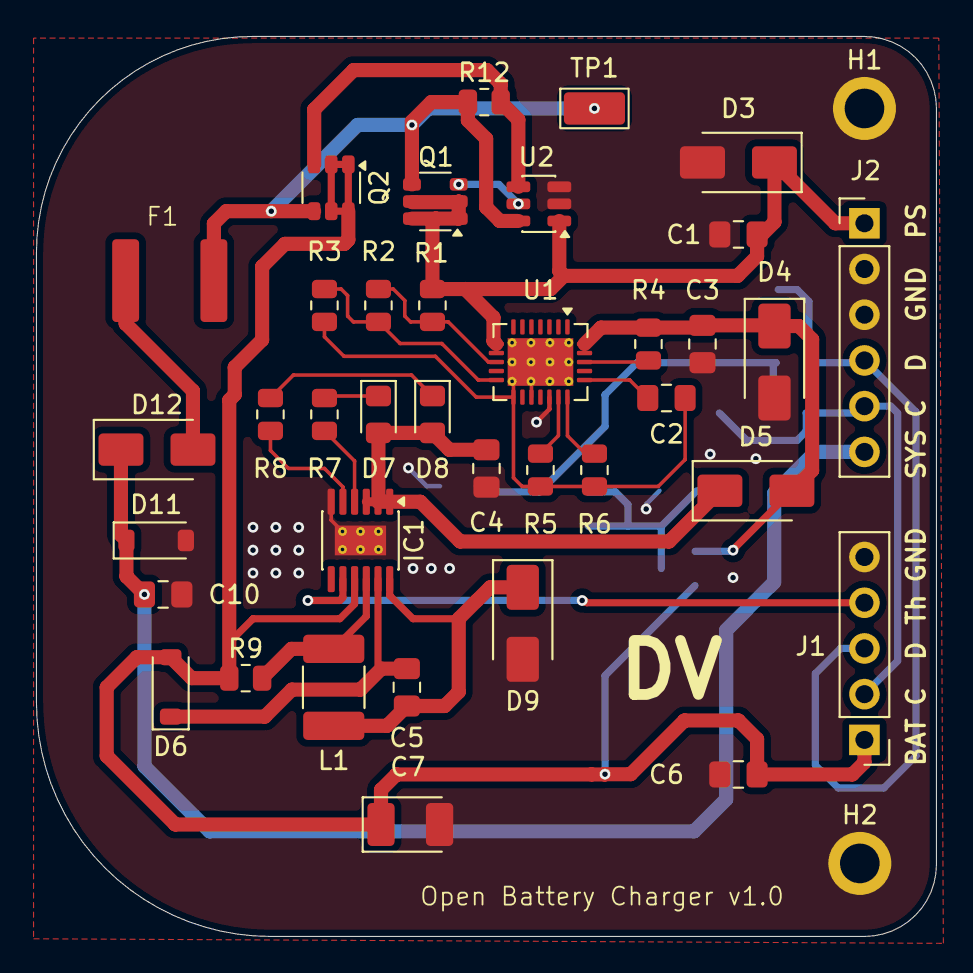
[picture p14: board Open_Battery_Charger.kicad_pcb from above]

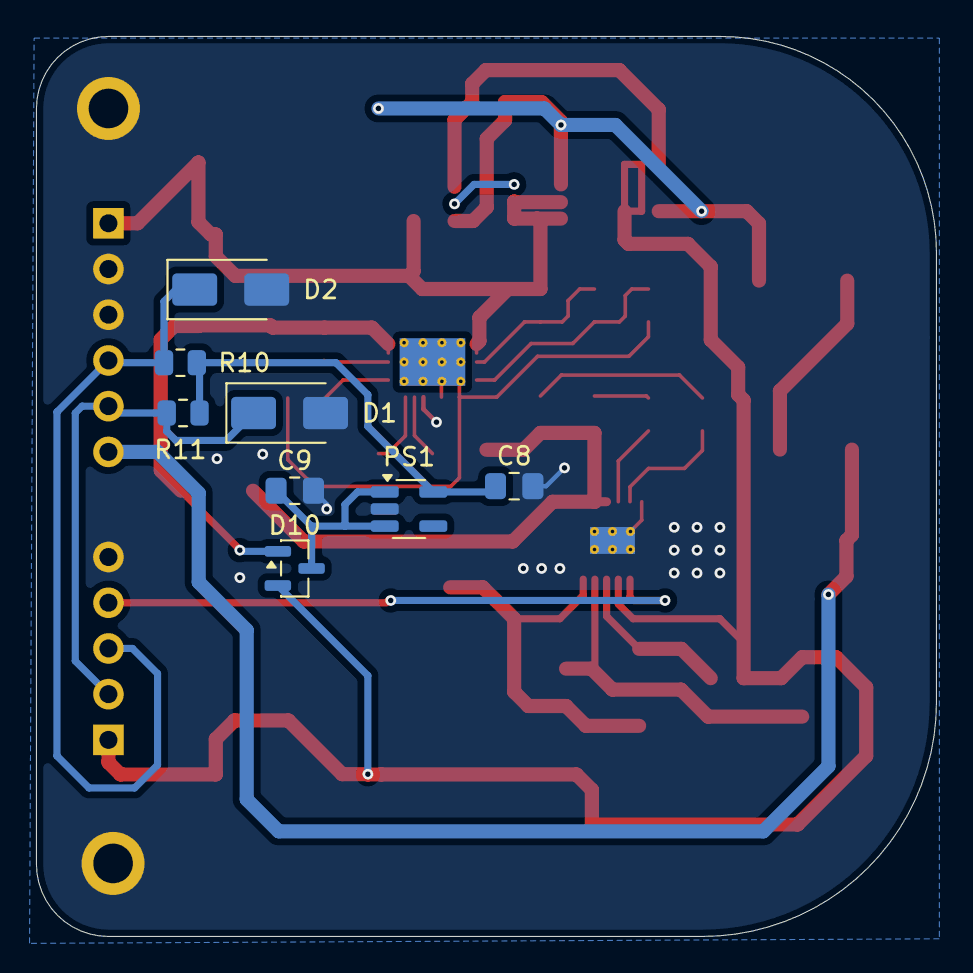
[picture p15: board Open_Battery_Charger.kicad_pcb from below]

Board: 2 copper layers, 50.0 x 50.0 mm, 47 parts (8 on the bottom side), 29 nets.

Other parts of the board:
H1, H2: MountingHole_2.2mm_M2_ISO7380_Pad

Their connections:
GND: H1.1, H2.2; also elsewhere on the board

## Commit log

2026-05-22 Project upload
    [Open_Battery_Charger-B_Cu.gbr, Open_Battery_Charger-B_Mask.gbr, Open_Battery_Charger-B_Paste.gbr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]
2026-05-22 schematic.png added
2026-05-25 New update 25.05.2026
    [Open_Battery_Charger.kicad_sch]
